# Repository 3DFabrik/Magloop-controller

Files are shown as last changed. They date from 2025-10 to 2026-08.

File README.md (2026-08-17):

# Magloop-Controller V25.00

Steuersoftware für einen **variablen Kondensator** (Magnetloop) mit **ESP32 WROOM**, **4x3-Keypad**, **128x64 OLED (SSD1306)** und **Endstop**.

Bedienung über das Tastenfeld und das OLED-Menü. Frequenz-/Schritt-Kalibrierung über WLAN-Webinterface. Frequenz-Tracking vom **Icom IC-705** über **Bluetooth Classic (SPP / CI-V)**.

Firmware: [`Steuersoftware_ESP32_V25_00/Steuersoftware_ESP32_V25_00.ino`](Steuersoftware_ESP32_V25_00/Steuersoftware_ESP32_V25_00.ino)

---

## Funktionen

- **Frequenzbasierte Positionierung** aus der Kalibrierungstabelle (lineare Interpolation)
- **Homing über Endstop** mit Backoff, langsamer Annäherung und Release (kein fester Absolutwert)
- **Backlash-Kompensation** beim Richtungswechsel
- **EEPROM**: letzte Position, Kalibrierpunkte, Motor-Running-Flag, Tracking und Bluetooth-Auto-Start
- **OLED + Keypad**: Menü, Frequenz, Position, IC-705-Status
- **Webinterface** nur für Setup/Kalibrierung (nicht für den Funkbetrieb)
- **IC-705-Tracking** über Bluetooth SPP, sobald Tracking eingeschaltet ist und das Funkgerät nicht sendet

WLAN und Bluetooth teilen sich das Funkmodul des ESP32. Es ist immer nur **eines von beiden** aktiv.

---

## Hardware (ESP32 WROOM)

| Komponente | Anschluss | GPIO |
|---|---|---|
| Keypad 4x3 | R1 / R2 / R3 / R4 | 25 / 26 / 33 / 32 |
| | C1 / C2 / C3 | 13 / 12 / 14 |
| Stepper (IN1–IN4) | A / B / C / D | 17 / 5 / 18 / 19 |
| OLED I²C | SDA / SCL | 21 / 22 |
| Endstop | Eingang, Pull-up | 4 |

---

## Kompilieren / Flashen

Board: `esp32:esp32:esp32`  
Partition: **`min_spiffs`** (sonst wird der Sketch zu groß)

```text
arduino-cli compile --fqbn "esp32:esp32:esp32:PartitionScheme=min_spiffs" -u -p COMx Steuersoftware_ESP32_V25_00/Steuersoftware_ESP32_V25_00.ino
```

Serial Monitor: **115200 Baud**.

---

## Alltag: Bluetooth / IC-705

Nach dem ersten erfolgreichen Bluetooth-Start merkt sich der Tuner das im EEPROM und kommt beim nächsten Einschalten direkt mit Bluetooth hoch (WLAN bleibt aus).

### Pairing am IC-705

1. Am Tuner Menü **5**, dann **1** (WLAN → Bluetooth)
2. Am IC-705: **MENU → SET → Bluetooth Set → Pairing/Connect → Device Search → Search Data Device**
3. Gerät **Magloop Tuner** wählen, PIN **0000**

Nicht gleichzeitig die Website und das IC-705 am Funkmodul nutzen.

### Tracking

Auf Seite **5**: Taste **0** schaltet Tracking ein/aus. Die Einstellung bleibt im EEPROM.  
Der Motor folgt der IC-705-QRG nur bei aktivem Tracking, verbundenem Funkgerät, RX (kein PTT) und stillstehendem Motor. Deadband standardmäßig **5 kHz**.

---

## Setup: WLAN / Webinterface

Für die Kalibrierung Bluetooth aus und WLAN an:

1. Menü **5**, Taste **1** (Bluetooth → WLAN)
2. WLAN **AntennaTuner**, Passwort **12345678**
3. Browser: **http://192.168.4.1**

Die Website hat **Home** und **Calibration** (Frequenz/Schritte). Bluetooth wird dort nicht mehr bedient.

`#` auf Seite 5 schaltet **nicht** mehr zwischen WLAN und Bluetooth. Dafür ist Taste **1**.

Nach dem Setup einfach neu starten oder erneut **1** drücken — Auto-Start bleibt gespeichert.

---

## Menü (OLED)

| Taste | Funktion |
|---|---|
| **1** | Automatik (Ziel-Frequenz) |
| **2** | Manuell |
| **3** | QRG speichern |
| **4** | Reset / Export |
| **5** | IC-705 / WLAN |

### Seite 5 (IC-705 / WLAN)

| Taste | Funktion |
|---|---|
| **0** | Tracking ein/aus (EEPROM) |
| **1** | Umschalten **WLAN ↔ Bluetooth** |
| **\*** | Zurück ins Hauptmenü |

Oben rechts erscheint kurz der Status (`BT an`, `WLAN an`, `Tracking AN`/`AUS`) anstelle von IDLE.

---

## Tasten allgemein

| Taste | Funktion |
|---|---|
| `*` | Abbrechen / Hauptmenü |
| `#` | Bestätigen / Motor stoppen |
| `0–9` | Zifferneingabe bzw. Menüwahl |
| `1 / 4 / 7` | Manuell eine Richtung (1 / 10 / 100 Schritte) |
| `3 / 6 / 9` | Manuell andere Richtung (1 / 10 / 100 Schritte) |
| `0` (manuell) | Homing |

---

## EEPROM

| Adresse | Zweck |
|---|---|
| `0` | Letzte Position |
| `4` | Anzahl Kalibrierpunkte |
| `100` | Kalibrierungstabelle |
| `1000` | Motor-Running-Flag (Not-Homing nach Stromausfall) |
| `1010` | BT-Settings: Tracking, Deadband, Auto-Start |

EEPROM-Größe: **4 KB**.

---

## Kalibrierung

Zwei Wege:

1. **Webinterface** (empfohlen): Homing, Motor per Buttons, Punkte speichern, Session committen oder verwerfen. Die bestehende Tabelle wird erst überschrieben, wenn gespeichert wird.
2. **Keypad Menü 3**: aktuelle Position mit Frequenz speichern.

Beim Reset (Menü 4, Code `1234`) werden zwei Standardpunkte gesetzt:

- `0 Schritte → 5150 kHz`
- `11640 Schritte → 24641 kHz`

Zwischenwerte werden linear interpoliert.

---

## Datenexport

Serial Monitor **115200 Baud**, Menü **Reset/Export**, Taste **0**:

```
--- START DATEN-EXPORT Kalibrierungstabelle ---
Index; Position (Schritte); Frequenz (kHz)
0; 0; 5150.0000
1; 11640; 24641.0000
--- ENDE DATEN-EXPORT ---
```

---

## Hinweise

- WLAN und Bluetooth nicht gleichzeitig — das ESP32-WROOM hat ein Funkmodul.
- Homing über den Endstop an GPIO 4.
- Kalibrierung per Export sichern.
- Nach Stromausfall während einer Fahrt startet ein Not-Homing.

---

## Version

**Projekt:** Magloop-Controller / Variablenkondensator-Steuerung  
**Version:** V25.00  
**Plattform:** ESP32 WROOM  
**Sprache:** C++ / Arduino  
**Lizenz:** Privatprojekt / Non-Commercial Use

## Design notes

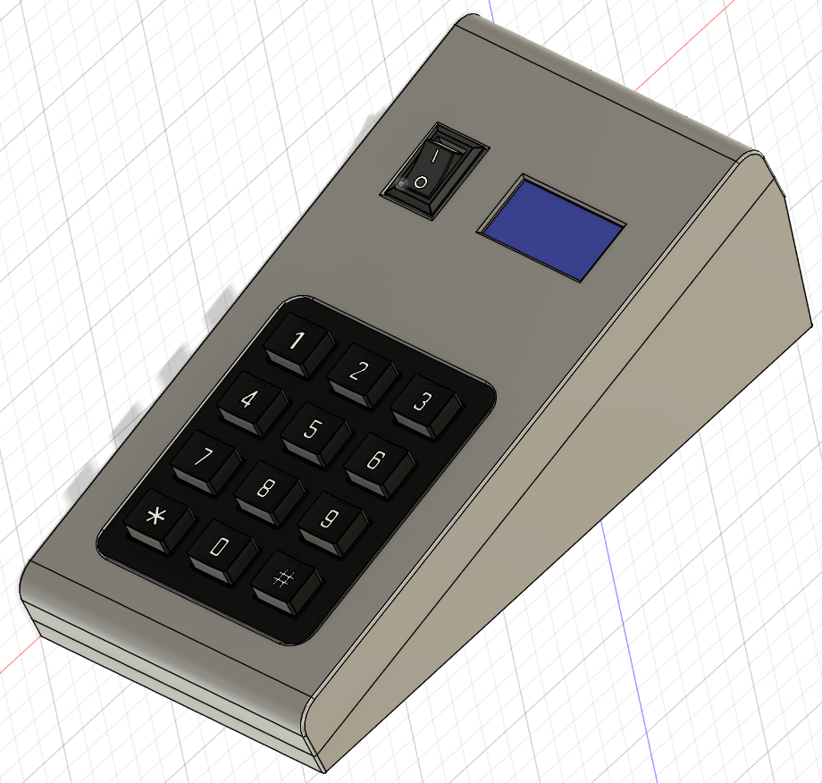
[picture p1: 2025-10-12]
Housing/CAD_Screenshot.png

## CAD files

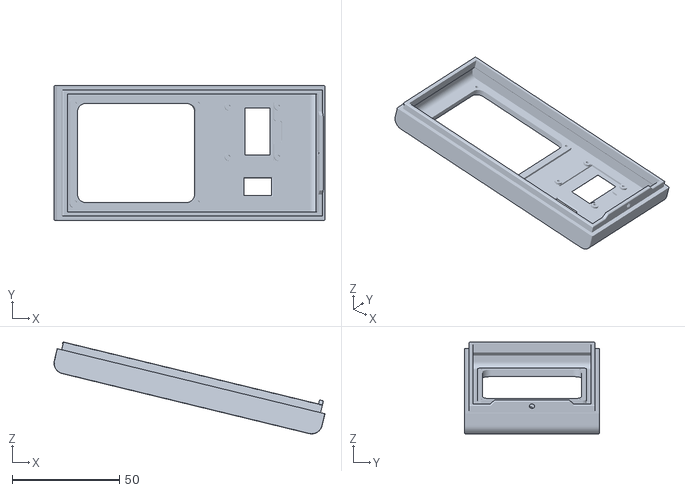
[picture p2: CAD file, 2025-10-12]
Housing/Top.stl
126.4 x 63.0 x 42.8

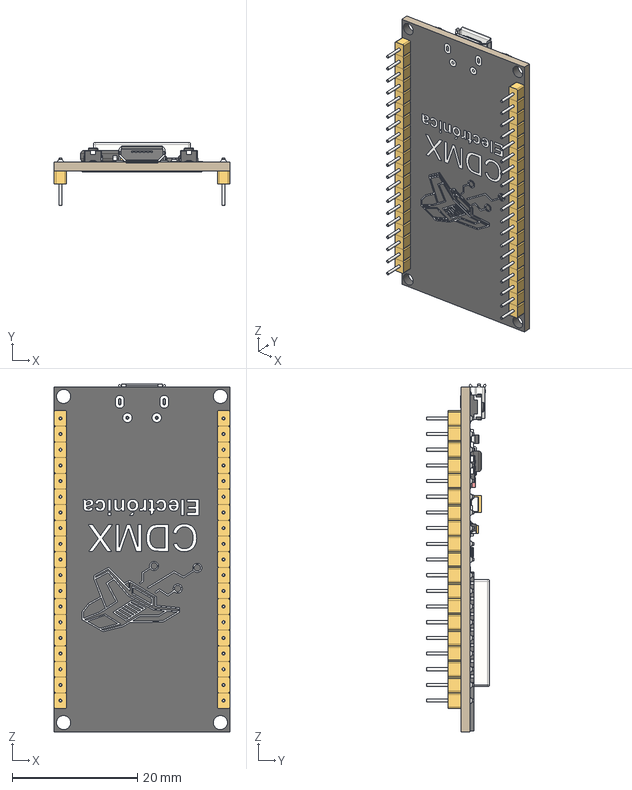
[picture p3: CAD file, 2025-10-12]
Parts/PCB_ESP32-38Pines.step
28.0 x 10.1 x 55.5 mm
MicroUSB
esp32
AMS1173.3V
cp2102
Push_Bottom x 2
Diodo_K24
Cap_Tam_106
Cap_Tam_106C
Transistor_smd x 2
Led_red_0603
Cap_0603 x 7
Res_102
Res_123 x 3
Res_471 x 4
Res_512 x 2

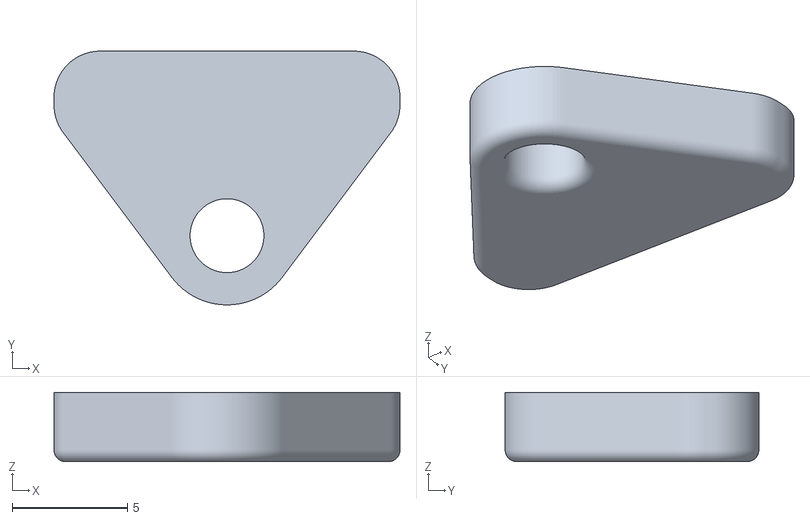
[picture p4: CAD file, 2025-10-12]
Housing/Housing_clamp_ESP.stl
15.0 x 11.0 x 3.00

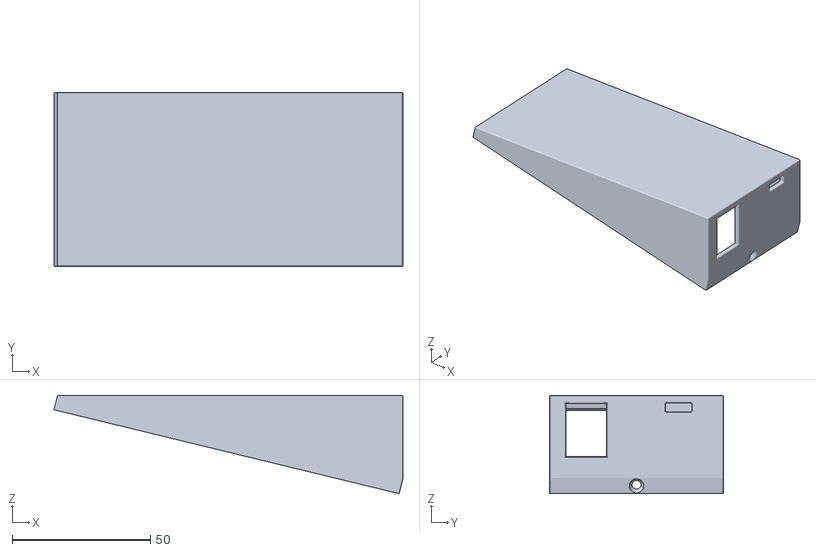
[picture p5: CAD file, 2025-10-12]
Housing/Bottom.stl
126.3 x 63.0 x 35.6

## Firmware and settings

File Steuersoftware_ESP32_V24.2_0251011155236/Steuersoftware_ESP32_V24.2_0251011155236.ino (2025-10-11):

/*
 ------------------------------------------------------------
 Projekt: Variablenkondensator-Steuerung V24.2
 ------------------------------------------------------------
 
 FUNKTIONSBESCHREIBUNG:
 Steuersoftware für einen Schrittmotor, der einen variablen Kondensator (VC)
 über einen ESP32 WROOM antreibt. Die Steuerung erfolgt über ein 4x3 Tastenfeld
 und einem 128x64 OLED-Display (SSD1306).
 - Frequenzbasierte Positionierung mittels Kalibrierungstabelle (EEPROM).
 - Homing (Referenzfahrt) zur Bestimmung des Nullpunktes.
 - Backlash-Kompensation bei Richtungswechsel (Wegfahren vom Nullpunkt).
 
 PINOUT ESP32 WROOM:
 ------------------------------------------------------------
 TASTENFELD (KEYPAD 4x3):
 - R1: GPIO 25
 - R2: GPIO 26
 - R3: GPIO 33
 - R4: GPIO 32
 - C1: GPIO 13
 - C2: GPIO 12
 - C3: GPIO 14
 
 MOTOR (Stepper Driver):
 - A (IN1/Vio. Pin): GPIO 17
 - B (IN2/Vio. Pin): GPIO 5
 - C (IN3/Vio. Pin): GPIO 18
 - D (IN4/Vio. Pin): GPIO 19
 
 OLED DISPLAY (I2C):
 - SDA: GPIO 21
 - SCL: GPIO 22
 ------------------------------------------------------------
*/

#include <Keypad.h>
#include <EEPROM.h>
#include <ctype.h>
#include <vector> 
#include <algorithm>
#include <Wire.h>
#include <Adafruit_GFX.h>
#include <Adafruit_SSD1306.h>
#include <Fonts/FreeSansBold12pt7b.h> 
#define SCREEN_WIDTH 128 
#define SCREEN_HEIGHT 64 
#define OLED_RESET -1
Adafruit_SSD1306 display(SCREEN_WIDTH, SCREEN_HEIGHT, &Wire, OLED_RESET);
#define SERIAL_BAUDRATE 115200
#define I2C_SDA_PIN 21
#define I2C_SCL_PIN 22
const byte ROWS = 4;
const byte COLS = 3;
char keys[ROWS][COLS] = { { '1', '2', '3' }, { '4', '5', '6' }, { '7', '8', '9' }, { '*', '0', '#' } };
byte rowPins[ROWS] = {25, 26, 33, 32}; 
byte colPins[COLS] = {13, 12, 14};      
Keypad keypad = Keypad(makeKeymap(keys), rowPins, colPins, ROWS, COLS);
const int motorPins[] = {17, 5, 18, 19}; 
int stepSequence[8][4] = {
    {0, 1, 1, 1}, {0, 0, 1, 1}, {1, 0, 1, 1}, {1, 0, 0, 1}, 
    {1, 1, 0, 1}, {1, 1, 0, 0}, {1, 1, 1, 0}, {0, 1, 1, 0}  
}; 
volatile int currentStep = 0;
volatile bool motorAktiv = false;
const long gesamtSchritte = 11640;
const int BACKLASH_STEPS = 50; 
volatile long aktuellePosition = 0;
volatile long zielPosition = 0; 
volatile bool zielErreicht = false; 
volatile int manualGeschwindigkeit = 0;
volatile bool manualRichtungRechts = true;
volatile bool stoppenErzwungen = false;
volatile bool homingInitialisiert = false; 
volatile long stepsToDrive = 0; 
volatile bool manualDriving = false; 
volatile bool lastRichtungRechts = false; 
volatile long finalTargetPosition = 0; 
volatile bool isBacklashCorrectionNeeded = false; 
volatile bool backlashSequenceRunning = false; 
#define EEPROM_SIZE 4096 
#define ADRESSE_LETZTE_POSITION 0
#define ADRESSE_PUNKTE_ZAEHLER (ADRESSE_LETZTE_POSITION + sizeof(long)) 
#define ADRESSE_ERSTER_PUNKT 100 
#define MAX_SPEICHERPUNKTE 100 
#define ADRESSE_MOTOR_RUNNING_FLAG 1000 
struct Speicherpunkt {
    long position;      
    float frequenz;     
};
std::vector<Speicherpunkt> kalibrierTabelle; 
volatile bool cursorVisible = false;
unsigned long lastCursorToggle = 0;
const unsigned long cursorInterval = 500; 
enum MotorState { STATE_IDLE,
                  STATE_MANUAL_MOVE, 
                  STATE_TARGET_MOVE,
                  STATE_SAVING,
                  STATE_HOMING,
                  STATE_BACKLASH_CORRECTION 
                }; 
MotorState currentMotorState = STATE_IDLE; 
enum MenuPage { PAGE_MENU = 0,             
                PAGE_MANUAL = 1,           
                PAGE_QRG_TARGET = 2,       
                PAGE_QRG_SAVE = 3,         
                PAGE_INIT = 4,             
                PAGE_INIT_CONFIRM = 5,     
                MAX_PAGE_COUNT = 6 };       
MenuPage currentPage = PAGE_MENU;           
String eingabePuffer = "";
String statusMeldung = "System Start..."; 
unsigned long lastDisplayUpdate = 0;
const unsigned long displayInterval = 250;
unsigned long statusMeldungEnde = 0; 
void updateDisplay();
void drawPositionBar();
void processKeypad(char taste);
void motorStop();
void saveCurrentPosition(); 
void loadKalibrierTabelle();
void sortKalibrierTabelle();
float getPositionFromFrequency(float frequenz);
float getFrequencyFromPosition(long position); 
void saveSpeicherpunkt(long pos, float freq);
void resetKalibrierung(); 
void startBacklashMove(long newTargetPos, long schritte); 
void setStatusMessage(String msg, unsigned int durationMs); 
void jumpToPage(MenuPage targetPage); 

void motorTask(void* pvParameters) {
  unsigned long lastStepTime = 0;
  for (;;) {
    if (motorAktiv) {
      
      int interval;
      if (manualGeschwindigkeit == 1) {
          interval = 5;  
      } else if (manualGeschwindigkeit == 2) {
          interval = 5;  
      } else { 
          interval = 4;  
      }
      if (millis() - lastStepTime >= interval) {
        lastStepTime = millis();
        bool richtungRechts = manualRichtungRechts;
        if (manualDriving && stepsToDrive <= 0) {
            motorAktiv = false; 
            vTaskDelay(1 / portTICK_PERIOD_MS);
            continue;
        }
        
        if (currentMotorState != STATE_HOMING && currentMotorState != STATE_BACKLASH_CORRECTION) {
            if ((richtungRechts && aktuellePosition <= 0) || 
                (!richtungRechts && aktuellePosition >= gesamtSchritte)) 
            {
                motorAktiv = false; 
                aktuellePosition = constrain(aktuellePosition, 0L, gesamtSchritte); 
                vTaskDelay(1 / portTICK_PERIOD_MS);
                continue;
            }
        }
        
        currentStep = richtungRechts ? (currentStep - 1 + 8) % 8 : (currentStep + 1) % 8;
        for (int i = 0; i < 4; i++) {
          digitalWrite(motorPins[i], stepSequence[currentStep][i]);
        }
        
        aktuellePosition += richtungRechts ? -1 : 1; 
        
        if (currentMotorState == STATE_HOMING || currentMotorState == STATE_BACKLASH_CORRECTION) {
            aktuellePosition = constrain(aktuellePosition, 0L - BACKLASH_STEPS, gesamtSchritte + BACKLASH_STEPS); 
        } else {
            aktuellePosition = constrain(aktuellePosition, 0L, gesamtSchritte);
        }
        
        if (manualDriving && stepsToDrive > 0) {
            stepsToDrive--;
        }
      }
    } else {
      for (int i = 0; i < 4; i++) {
        digitalWrite(motorPins[i], LOW); 
      }
    }
    vTaskDelay(1 / portTICK_PERIOD_MS);
  }
}
void motorStop() {
  motorAktiv = false;
  stoppenErzwungen = false;
  stepsToDrive = 0;
  manualDriving = false;
  
  if (currentMotorState != STATE_HOMING && currentMotorState != STATE_BACKLASH_CORRECTION) {
      aktuellePosition = constrain(aktuellePosition, 0L, gesamtSchritte);
  }
  
  bool running = false;
  EEPROM.put(ADRESSE_MOTOR_RUNNING_FLAG, running);
  EEPROM.commit();
}
void saveCurrentPosition() {
    long positionToSave = constrain(aktuellePosition, 0L, gesamtSchritte);
    EEPROM.put(ADRESSE_LETZTE_POSITION, positionToSave);
    EEPROM.commit();
}
void startBacklashMove(long newTargetPos, long schritte) {
    zielPosition = newTargetPos;
    stepsToDrive = schritte;
    
    bool newDirectionRight = (zielPosition < aktuellePosition); 
    manualRichtungRechts = newDirectionRight;
    lastRichtungRechts = newDirectionRight; 
    manualGeschwindigkeit = 3; 
    manualDriving = (schritte > 0); 
    motorAktiv = true;
    
    if (currentMotorState != STATE_BACKLASH_CORRECTION) { 
      bool running = true;
      EEPROM.put(ADRESSE_MOTOR_RUNNING_FLAG, running); 
      EEPROM.commit();
    }
}
void setStatusMessage(String msg, unsigned int durationMs) {
    statusMeldung = msg;
    statusMeldungEnde = millis() + durationMs;
}
void jumpToPage(MenuPage targetPage) {
    currentPage = targetPage;
    eingabePuffer = "";
    stoppenErzwungen = false;
}
void setup() {
  Serial.begin(SERIAL_BAUDRATE);
  Serial.println("\n--- ESP32 WROOM System Start (V24.0) ---");
  Wire.begin(I2C_SDA_PIN, I2C_SCL_PIN);
  
  if (!display.begin(SSD1306_SWITCHCAPVCC, 0x3C)) { 
    Serial.println(F("SSD1306 allocation failed"));
    for(;;); 
  }
  
  display.setRotation(2); 
  
  display.display(); 
  display.clearDisplay();
  display.setTextSize(1);
  display.setTextColor(SSD1306_WHITE); 
  display.setCursor(0,0);
  display.println("INIT OK");
  display.display();
  delay(1000); 
  for (int i = 0; i < 4; i++) pinMode(motorPins[i], OUTPUT);
  
  for (int i = 0; i < 4; i++) digitalWrite(motorPins[i], LOW);
  
  EEPROM.begin(EEPROM_SIZE); 
  
  xTaskCreatePinnedToCore(
    motorTask,        
    "MotorControl",   
    2048,             
    NULL,             
    2,                
    NULL,             
    0                 
  );
  aktuellePosition = 0; 
  homingInitialisiert = false; 
  int anzahlPunkte = 0;
  EEPROM.get(ADRESSE_PUNKTE_ZAEHLER, anzahlPunkte);
  
  if (anzahlPunkte < 2) { 
    resetKalibrierung(); 
    setStatusMessage("INIT: Freq. ges. H-Strt.", 2000); 
  } else {
    loadKalibrierTabelle(); 
    setStatusMessage("Tabelle geladen (" + String(kalibrierTabelle.size()) + " Pkt)", 2000); 
  }
  long lastKnownPosition = 0;
  bool wasRunning = false;
  
  EEPROM.get(ADRESSE_MOTOR_RUNNING_FLAG, wasRunning); 
  EEPROM.get(ADRESSE_LETZTE_POSITION, lastKnownPosition); 
  
  if (wasRunning) { 
      motorStop(); 
      aktuellePosition = gesamtSchritte + 50; 
      currentMotorState = STATE_HOMING; 
      setStatusMessage("Fehler! Not-Homing!", 2000); 
  }
  else if (lastKnownPosition >= 0 && lastKnownPosition <= gesamtSchritte) { 
      aktuellePosition = lastKnownPosition;
      currentMotorState = STATE_IDLE; 
  } else {
      aktuellePosition = gesamtSchritte + 50; 
      currentMotorState = STATE_HOMING; 
      setStatusMessage("Homing startet...", 2000); 
  }
  
  currentPage = PAGE_MENU; 
  updateDisplay(); 
}

void loop() {
  unsigned long jetzt = millis();
  char taste = keypad.getKey();
  if (jetzt - lastCursorToggle >= cursorInterval) {
    lastCursorToggle = jetzt;
    cursorVisible = !cursorVisible;
  }
  if (taste == '*') {
    if (motorAktiv) {
      motorStop();
      stoppenErzwungen = true;
      currentMotorState = STATE_IDLE;
      saveCurrentPosition(); 
    } else {
      if (currentPage == PAGE_INIT_CONFIRM) {
          jumpToPage(PAGE_INIT); 
      } else {
          jumpToPage(PAGE_MENU); 
      }
    }
  }

  if (taste == '#') {
     if (currentMotorState == STATE_HOMING || currentMotorState == STATE_TARGET_MOVE || currentMotorState == STATE_MANUAL_MOVE || currentMotorState == STATE_BACKLASH_CORRECTION) {
        
        // Neu: Prüfen, ob der abgebrochene Zustand Homing war
        bool wasHoming = (currentMotorState == STATE_HOMING); 
        
        motorStop();
        stoppenErzwungen = true;
        
        if (wasHoming) {
           // FIX V24.3: P=0 wird erzwungen und homingInitialisiert zurückgesetzt.
           aktuellePosition = 0; 
           homingInitialisiert = false; // <<< Wichtig: Homing-Flag zurücksetzen
           setStatusMessage("STOP (P=0 gesetzt)", 2000);
        } else {
           // Optionale Meldung für andere Abbrüche
           setStatusMessage("Bewegung gestoppt", 1000);
        }
        
        currentMotorState = STATE_IDLE;
        saveCurrentPosition(); 
        
    } else {
      processKeypad(taste);
    }
  } else {
    // Dieser Teil bleibt unverändert, um andere Tasten zu verarbeiten
    processKeypad(taste);
  }
  if (statusMeldungEnde > 0 && jetzt >= statusMeldungEnde) {
      statusMeldungEnde = 0;
      statusMeldung = ""; 
      if (currentPage == PAGE_INIT_CONFIRM) {
          jumpToPage(PAGE_MENU); 
      }
  }

  switch (currentMotorState) {
    case STATE_IDLE:
      if (stepsToDrive > 0) {
          currentMotorState = STATE_MANUAL_MOVE;
          manualDriving = true;
          motorAktiv = true;
          bool running = true;
          EEPROM.put(ADRESSE_MOTOR_RUNNING_FLAG, running); 
          EEPROM.commit();
      }
      break;
    case STATE_MANUAL_MOVE:
      if (!motorAktiv && manualDriving) {
          
          if (backlashSequenceRunning) {
              aktuellePosition = finalTargetPosition; 
              backlashSequenceRunning = false;
          }
          
          motorStop(); 
          currentMotorState = STATE_IDLE;
          manualDriving = false;
          saveCurrentPosition(); 
      } else if (!manualDriving) {
          motorStop();
          currentMotorState = STATE_IDLE;
      }
      break;
    case STATE_TARGET_MOVE:
        if (!motorAktiv && !zielErreicht) {
            
            float zielFloat = eingabePuffer.toFloat();
            eingabePuffer = ""; 
            
            finalTargetPosition = (long)round(getPositionFromFrequency(zielFloat)); 
            
            if (aktuellePosition == finalTargetPosition) {
                zielErreicht = true;
                break; 
            }
            
            bool zielRichtungRechts = (finalTargetPosition < aktuellePosition); 
            
            if (!zielRichtungRechts) {
                isBacklashCorrectionNeeded = false;
                backlashSequenceRunning = false; 
                currentMotorState = STATE_MANUAL_MOVE; 
                startBacklashMove(finalTargetPosition, abs(finalTargetPosition - aktuellePosition));
            } else {
                isBacklashCorrectionNeeded = true;
                long tempTarget = finalTargetPosition - BACKLASH_STEPS;
                
                currentMotorState = STATE_BACKLASH_CORRECTION; 
                startBacklashMove(tempTarget, abs(tempTarget - aktuellePosition));
            }
        }
        if (currentMotorState == STATE_MANUAL_MOVE && !isBacklashCorrectionNeeded) {
            bool zielUeberfahren = (manualRichtungRechts && aktuellePosition <= zielPosition) || 
                                   (!manualRichtungRechts && aktuellePosition >= zielPosition);
            if (zielUeberfahren) {
                motorStop();
                aktuellePosition = finalTargetPosition;
                zielErreicht = true;
                currentMotorState = STATE_IDLE;
                saveCurrentPosition(); 
            }
        } else if (zielErreicht) {
            zielErreicht = false;
            currentMotorState = STATE_IDLE;
        }
        break;
        
    case STATE_BACKLASH_CORRECTION:
        if (!motorAktiv) { 
            
            if (isBacklashCorrectionNeeded) {
                
                isBacklashCorrectionNeeded = false; 
                
                if (finalTargetPosition <= BACKLASH_STEPS) {
                    aktuellePosition = 0; 
                    
                } else {
                    currentMotorState = STATE_MANUAL_MOVE;
                    long stepsBack = abs(finalTargetPosition - aktuellePosition); 
                    startBacklashMove(finalTargetPosition, stepsBack);
                    backlashSequenceRunning = true; 
                }
            } 
            
            if (currentMotorState == STATE_BACKLASH_CORRECTION) { 
                motorStop(); 
                currentMotorState = STATE_IDLE;
                backlashSequenceRunning = false;
                saveCurrentPosition(); 
            }
        }
        break;
        
    case STATE_SAVING:
      {
        float freqToSave = eingabePuffer.toFloat();
        saveSpeicherpunkt(aktuellePosition, freqToSave);
        eingabePuffer = ""; 
        currentMotorState = STATE_IDLE;
        saveCurrentPosition(); 
        break;
      }
      
    case STATE_HOMING: 
        if (!homingInitialisiert) {
            manualRichtungRechts = true; 
            manualGeschwindigkeit = 1; 
            motorAktiv = true;
            homingInitialisiert = true;
            lastRichtungRechts = true; 
            stepsToDrive = 0; 
            manualDriving = false; 
        }
        if (aktuellePosition <= (0L - BACKLASH_STEPS)) { 
              motorStop();
              aktuellePosition = 0; 
              saveCurrentPosition(); 
              
              homingInitialisiert = false;
              currentMotorState = STATE_IDLE;
              setStatusMessage("HOMING abgeschlossen (P=0)", 2000); 
        }
        break;
    default:
      break;
  }
  if (jetzt - lastDisplayUpdate >= displayInterval) {
    lastDisplayUpdate = jetzt;
    updateDisplay();
  }
  delay(1);
}

void processKeypad(char taste) {
    if (!taste || taste == '*' || taste == '#') {
        
        if (taste == '#') {
            if (currentPage == PAGE_QRG_TARGET && eingabePuffer.length() > 0 && currentMotorState == STATE_IDLE) {
                currentMotorState = STATE_TARGET_MOVE; 
                return; 
            } else if (currentPage == PAGE_QRG_SAVE && eingabePuffer.length() > 0 && currentMotorState == STATE_IDLE) {
                currentMotorState = STATE_SAVING;
                return;
            } else if (currentPage == PAGE_INIT) { 
                if (currentMotorState == STATE_IDLE) {
                    jumpToPage(PAGE_INIT_CONFIRM);
                    return;
                }
            } else if (currentPage == PAGE_INIT_CONFIRM) {
                if (eingabePuffer == "1234") {
                    resetKalibrierung(); 
                    setStatusMessage("RESET ERFOLGREICH!", 3000); 
                } else {
                    setStatusMessage("Falscher Code!", 2000); 
                    eingabePuffer = "";
                }
                return;
            }
        }
        return;
    }
    if (taste >= '0' && taste <= '9') {
        
        if (currentPage == PAGE_MENU) {
            if (taste == '1') {
                jumpToPage(PAGE_QRG_TARGET); 
            } else if (taste == '2') {
                jumpToPage(PAGE_MANUAL); 
            } else if (taste == '3') {
                jumpToPage(PAGE_QRG_SAVE); 
            } else if (taste == '4') { // Menüpunkt 5 wurde entfernt, 4 ist jetzt der letzte Punkt
                jumpToPage(PAGE_INIT); 
            }
            return;
        }
        
        switch (currentPage) {
            case PAGE_MANUAL:
                if (taste == '1' || taste == '4' || taste == '7' || taste == '3' || taste == '6' || taste == '9') {
                    
                    long schritte;
                    int geschw;
                    if (taste == '1' || taste == '3') {
                        schritte = 1; 
                        geschw = 1; 
                    } else if (taste == '4' || taste == '6') {
                        schritte = 10; 
                        geschw = 2; 
                    } else if (taste == '7' || taste == '9') {
                        schritte = 100; 
                        geschw = 3; 
                    } else {
                        return;
                    }
                    bool rechtsTaste = (taste == '3' || taste == '6' || taste == '9');
                    bool neueRichtungRechts = !rechtsTaste; 
                    if (currentMotorState == STATE_IDLE) {
                        finalTargetPosition = aktuellePosition + (rechtsTaste ? schritte : -schritte);
                        
                        if (!neueRichtungRechts) {
                            isBacklashCorrectionNeeded = false;
                            backlashSequenceRunning = false; 
                            currentMotorState = STATE_MANUAL_MOVE;
                            startBacklashMove(finalTargetPosition, schritte);
                        } else {
                            isBacklashCorrectionNeeded = true;
                            long tempTarget = finalTargetPosition - BACKLASH_STEPS;
                            
                            currentMotorState = STATE_BACKLASH_CORRECTION;
                            startBacklashMove(tempTarget, abs(tempTarget - aktuellePosition));
                        }
                    } else {
                    }
                } 
                else if (taste == '0') {
                    if (!motorAktiv) {
                        aktuellePosition = gesamtSchritte + 50; 
                        homingInitialisiert = false; 
                        currentMotorState = STATE_HOMING;
                    } else {
                    }
                }
                break;
            case PAGE_QRG_TARGET:
            case PAGE_QRG_SAVE:
                if (eingabePuffer.length() < 5) { 
                    eingabePuffer += taste;
                }
                break;
                
            case PAGE_INIT_CONFIRM:
                if (eingabePuffer.length() < 4) { 
                    eingabePuffer += taste;
                }
                break;
            case PAGE_INIT: // NEU: '0' für Export
                if (taste == '0' && currentMotorState == STATE_IDLE) { 
                    dumpKalibrierTabelle();
                    return;
                }
                break;
            case PAGE_MENU: 
                break;
        }
    }
}

void loadKalibrierTabelle() {
    kalibrierTabelle.clear();
    int anzahlPunkte = 0;
    EEPROM.get(ADRESSE_PUNKTE_ZAEHLER, anzahlPunkte);
    if (anzahlPunkte < 2) return; 
    Speicherpunkt tempPunkt;
    for (int i = 0; i < anzahlPunkte; ++i) {
        EEPROM.get(ADRESSE_ERSTER_PUNKT + i * sizeof(Speicherpunkt), tempPunkt);
        kalibrierTabelle.push_back(tempPunkt);
    }
    sortKalibrierTabelle();
}
void resetKalibrierung() {
    kalibrierTabelle.clear();
    saveSpeicherpunkt(0, 5150.0f);                   // Start bei 0 Schritten
    saveSpeicherpunkt(gesamtSchritte, 24641.0f);     // Ende bei 11640 Schritten
    EEPROM.commit();
}
void sortKalibrierTabelle() {
    std::sort(kalibrierTabelle.begin(), kalibrierTabelle.end(), [](const Speicherpunkt& a, const Speicherpunkt& b) {
        return a.position < b.position;
    });
}
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

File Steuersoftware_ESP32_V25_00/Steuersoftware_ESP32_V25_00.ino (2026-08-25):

/*
 ------------------------------------------------------------
 Projekt: Variablenkondensator-Steuerung V25.00
 ------------------------------------------------------------

 FUNKTIONSBESCHREIBUNG:
 Steuersoftware für einen Schrittmotor, der einen variablen Kondensator (VC)
 über einen ESP32 WROOM antreibt. Die Steuerung erfolgt über ein 4x3 Tastenfeld
 und einem 128x64 OLED-Display (SSD1306) sowie über eine Web-Schnittstelle.
 - Frequenzbasierte Positionierung mittels Kalibrierungstabelle (EEPROM).
 - Homing: schnell zum Endschalter, langsam ein Stück darüber, langsam
   hoch bis der Schalter öffnet = Position 0.
 - Backlash-Kompensation bei Richtungswechsel (Wegfahren vom Nullpunkt).
 - Web-Schnittstelle zur Steuerung und voll-manuellen Kalibrierung über WLAN.
 - Kalibrierungspunkte werden in 50kHz Schritten innerhalb der Ham-Bänder
   und in 500kHz Schritten dazwischen generiert.

 PINOUT ESP32 WROOM:
 ------------------------------------------------------------
 TASTENFELD (KEYPAD 4x3):
 - R1: GPIO 25
 - R2: GPIO 26
 - R3: GPIO 33
 - R4: GPIO 32
 - C1: GPIO 13
 - C2: GPIO 12
 - C3: GPIO 14

 MOTOR (Stepper Driver):
 - A (IN1/Vio. Pin): GPIO 17
 - B (IN2/Vio. Pin): GPIO 5
 - C (IN3/Vio. Pin): GPIO 18
 - D (IN4/Vio. Pin): GPIO 19

 OLED DISPLAY (I2C):
 - SDA: GPIO 21
 - SCL: GPIO 22
 ------------------------------------------------------------
*/

#include <Adafruit_GFX.h>
#include <Adafruit_SSD1306.h>
#include <BluetoothSerial.h>
#include <EEPROM.h>
#include "esp_coexist.h"
#include "esp_wifi.h"
#include <Fonts/FreeSansBold12pt7b.h>
#include <Keypad.h>
#include <WebServer.h>
#include <WebSocketsServer.h> // WebSocket library - https://github.com/Links2004/arduinoWebSockets
#include <WiFi.h>
#include <Wire.h>
#include <algorithm>
#include <ctype.h>
#include <math.h>
#include <set> // Required for the new calibration logic
#include <vector>


// Display configuration
#define SCREEN_WIDTH 128
#define SCREEN_HEIGHT 64
#define OLED_RESET -1
Adafruit_SSD1306 display(SCREEN_WIDTH, SCREEN_HEIGHT, &Wire, OLED_RESET);

// Serial and I2C configuration
#define SERIAL_BAUDRATE 115200
#define I2C_SDA_PIN 21
#define I2C_SCL_PIN 22

// Endstop configuration
#define ENDSTOP_PIN 4 // GPIO4 für Endstop
volatile bool endstopTriggered = false;
void IRAM_ATTR endstopISR() {
  endstopTriggered = true; // nur Flag setzen
}

// Keypad configuration
const byte ROWS = 4;
const byte COLS = 3;
char keys[ROWS][COLS] = {
    {'1', '2', '3'}, {'4', '5', '6'}, {'7', '8', '9'}, {'*', '0', '#'}};
byte rowPins[ROWS] = {25, 26, 33, 32};
byte colPins[COLS] = {13, 12, 14};
Keypad keypad = Keypad(makeKeymap(keys), rowPins, colPins, ROWS, COLS);

// Motor configuration
const int motorPins[] = {17, 5, 18, 19};
// Step sequence
int stepSequence[8][4] = {{0, 1, 1, 0}, {1, 1, 1, 0}, {1, 1, 0, 0},
                          {1, 1, 0, 1}, {1, 0, 0, 1}, {1, 0, 1, 1},
                          {0, 0, 1, 1}, {0, 1, 1, 1}};

// Motor state variables
const long gesamtSchritte = 11640;
// Must be at least the real gear lash, otherwise a reversal is swallowed whole
// and the capacitor never moves. Overshooting it cancels out exactly, so this
// is deliberately generous.
const int BACKLASH_STEPS = 60;
const int HOMING_BACKOFF_STEPS = 200;
const int HOMING_CLEAR_EXTRA = 20;
const int HOMING_CLEAR_MAX_STEPS = 200;
const int HOMING_SEEK_MAX_STEPS = 200;
const uint8_t HOMING_PRESS_DEBOUNCE = 8;
const uint8_t HOMING_OPEN_DEBOUNCE = 3;
const uint8_t HOMING_ZERO_DEBOUNCE = 3;
const long RTEST_HIGH_POS = 4000;
const long RTEST_LOW_POS = 400;
const int RTEST_DEFAULT_CYCLES = 5;
const int RTEST_MAX_CYCLES = 20;
const unsigned long RTEST_MOVE_TIMEOUT_MS = 90000;

// Motor speed constants
const int SPEED_FAST = 2;   // Fast speed for initial homing
const int SPEED_NORMAL = 3; // Normal speed for regular movement
const int SPEED_SLOW = 16;  // Slow speed for precise homing
const int SPEED_CAL = 32;   // Slow cal fine-search / dip approach

// Started from standstill at full rate the rotor lags the field and a short
// move ends before it catches up. Ease into the target rate instead.
const int RAMP_START_MS = 16;
const int RAMP_STEPS = 40;
// Hold the last phase briefly so the rotor pulls in before the field goes
// away, otherwise it drops back to the nearest detent and the step is lost.
const int MOTOR_SETTLE_MS = 80;

// Backlash compensation state variables
volatile bool motorJobActive = false;
volatile long motorFinalGoal = -1;
volatile int motorLegSpeed = SPEED_NORMAL;
volatile long motorRampLeft = 0;
// True after a completed move that finished approaching from below (UP).
volatile bool settledFromBelow = false;

// Simplified Motor State Machine
enum MotorState {
  MOTOR_IDLE,
  MOTOR_HOMING,
  MOTOR_HOMING_AT_ENDSTOP,
  MOTOR_MOVING
};

enum HomingPhase {
  HOMING_APPROACH,  // Down until switch closes
  HOMING_CLEAR,     // Up until open, then HOMING_CLEAR_EXTRA
  HOMING_SLOW_SEEK  // Slow down until close = position 0
};

enum RepeatTestState {
  RTEST_IDLE,
  RTEST_WAIT_REF_HOME,
  RTEST_GO_HIGH,
  RTEST_WAIT_HIGH,
  RTEST_GO_LOW,
  RTEST_WAIT_LOW,
  RTEST_WAIT_FINAL_HOME
};

enum Direction {
  DIR_UP,  // Away from endstop (higher position / higher frequency)
  DIR_DOWN // Towards endstop (lower position / lower frequency)
};

enum MotorRunKind {
  MOTOR_RUN_HOME,
  MOTOR_RUN_RELATIVE,
  MOTOR_RUN_ABSOLUTE
};

// Motor state variables
volatile MotorState currentMotorState = MOTOR_IDLE;
volatile HomingPhase currentHomingPhase = HOMING_APPROACH;
volatile int currentStep = 0;
volatile bool motorAktiv = false;
volatile long aktuellePosition = 0;
volatile long targetPosition = 0;
volatile long stepsRemaining = 0;
volatile int currentSpeed = SPEED_NORMAL;
volatile Direction currentDirection = DIR_DOWN;
volatile bool endstopHit = false;
volatile bool homingSucceeded = false;
volatile bool homingContactLatched = false;
volatile bool homingClearOpenSeen = false;
volatile bool lastHomingErrorValid = false;
volatile long lastHomingError = 0;
RepeatTestState rtestState = RTEST_IDLE;
int rtestCycles = 0;
int rtestIndex = 0;
bool rtestSavedTracking = false;
unsigned long rtestWaitUntil = 0;
char serialLineBuf[48];
uint8_t serialLineLen = 0;

// EEPROM configuration
#define EEPROM_SIZE 4096
#define ADRESSE_LETZTE_POSITION 0
#define ADRESSE_PUNKTE_ZAEHLER (ADRESSE_LETZTE_POSITION + sizeof(long))
#define ADRESSE_ERSTER_PUNKT 100
#define MAX_SPEICHERPUNKTE 100
#define ADRESSE_MOTOR_RUNNING_FLAG 1000
#define ADRESSE_BT_SETTINGS 1010
#define ADRESSE_BT_PEER 1020
#define BT_SETTINGS_MAGIC 0xB3
#define BT_SETTINGS_MAGIC_V2 0xB2
#define BT_SETTINGS_MAGIC_V1 0xB1
#define BT_PEER_MAGIC 0xC7
// V2 records carry the RFCOMM channel that actually delivered CI-V.
#define BT_PEER_MAGIC_V2 0xC8
#define BT_DEADBAND_MIN_KHZ 1
#define BT_DEADBAND_MAX_KHZ 1
#define BT_DEADBAND_DEFAULT_KHZ 1
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

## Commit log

2025-10-12 3D-Printed housing parts added
    [Bottom.stl, Housing_clamp_ESP.stl, PCB_ESP32-38Pines.step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]
2026-08-16 Add ESP32 firmware V25.00 with web interface and endstop homing.
2026-08-17 Fix BT auto-start boot loop and persist tracking in EEPROM.
    [Steuersoftware_ESP32_V25_00.ino]
2026-08-17 Update README for V25 Bluetooth tracking and web calibration.
2026-08-19 Always approach motor targets from below, including keypad jogs.
    Unknown backlash after a down-move or abort is cleared before the final up-approach, and the manual OLED refreshes faster while driving.
    [Steuersoftware_ESP32_V25_00.ino]
2026-08-20 Add OLED result window and set homing zero when the endstop opens.
2026-08-23 Rework homing into approach/clear/slow-seek phases with ramped motor legs.
    Route all motor moves through a single arm/finish path, add a start ramp,
    halve the backlash compensation and retune the autocal sweep margins.
    [Steuersoftware_ESP32_V25_00.ino]
2026-08-23 Slow the cal approach, animate motor direction and remember the CI-V channel.
    Raise the step pauses for homing fine seek, cal fine search and the sweep
    near the dip. Replace the static RUN label with arrows that drift in the
    travel direction at a rate following the step pause. Persist the RFCOMM
    channel that actually delivered CI-V so a reconnect skips the channel scan,
    and cut the Bluetooth auto-start delays.
    [Steuersoftware_ESP32_V25_00.ino]
2026-08-23 Land the tuning dip accurately and stop crawling to the sweep start
    The gear lash turned out to be larger than the 25 steps of compensation,
    so a direction reversal was swallowed whole: the counter advanced while
    the capacitor stood still. Any target approached from above was therefore
    missed by an unpredictable amount, which is why the SWR sometimes sat far
    off after a move. Overshooting the lash cancels out exactly while
    undershooting ruins the move, so the compensation is now deliberately
    generous at 60 steps.
    The swept minimum was also recorded against the live position although
    the reading it came from was a poll interval plus a Bluetooth round trip
    old, placing the dip tens of steps a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
    [Steuersoftware_ESP32_V25_00.ino]
2026-08-25 Detect the autocal dip from a rising SWR valley and keep the OLED from blocking the sweep.
    Coarse search can hand off a neighbourhood without already reaching SWR 2.0, I2C runs at 400 kHz so display redraws stop eating ~90 ms of loop time, and cal TX is temporarily ~1 W while we test 20 m crashes at resonance.
    [Steuersoftware_ESP32_V25_00.ino]
2026-08-25 Centre autocal on the SWR floor and resume tracking from the result screen.
    The sweep now slows below SWR 6, fine-searches only that window, and stores the middle of equal-minimum samples. Tracking follows the rig on the cal result page, and * returns to the IC-705 menu.
